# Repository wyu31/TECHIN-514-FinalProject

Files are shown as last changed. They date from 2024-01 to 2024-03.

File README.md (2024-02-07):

# TECHIN-514-FinalProject
This GitHub repository is for my TECHIN-514 final project and all my related files will be uploaded and updated to it.

## System Architecture with Diagram
### Slide 1 - Introduction
**Project Title**  
Finger Drumbeat

**Explanation**  
This is an IoT device set to add drum beats using hand gestures, allowing users to engage in existing music.

Generally, I want to achieve:
1. Different **fingertip accelerations** produce different **Stepper-motor-driven gauge needle** swing accelerations and different drum beat loudnesses (with **Speaker & Amplifier**).
2. Different **components of the drum** (Bass Drum, Tom-Tom Drum, Snare drum, Crash Cymbal, Ride Cymbal, Hi-Hat) are played under different **gestures**.
3. **OLED** screen displays the component currently being played.
4. **LED Array** randomly displays rhythm animation
5. **Button** can switch the random animations on the LED Array

**General Sketch**  
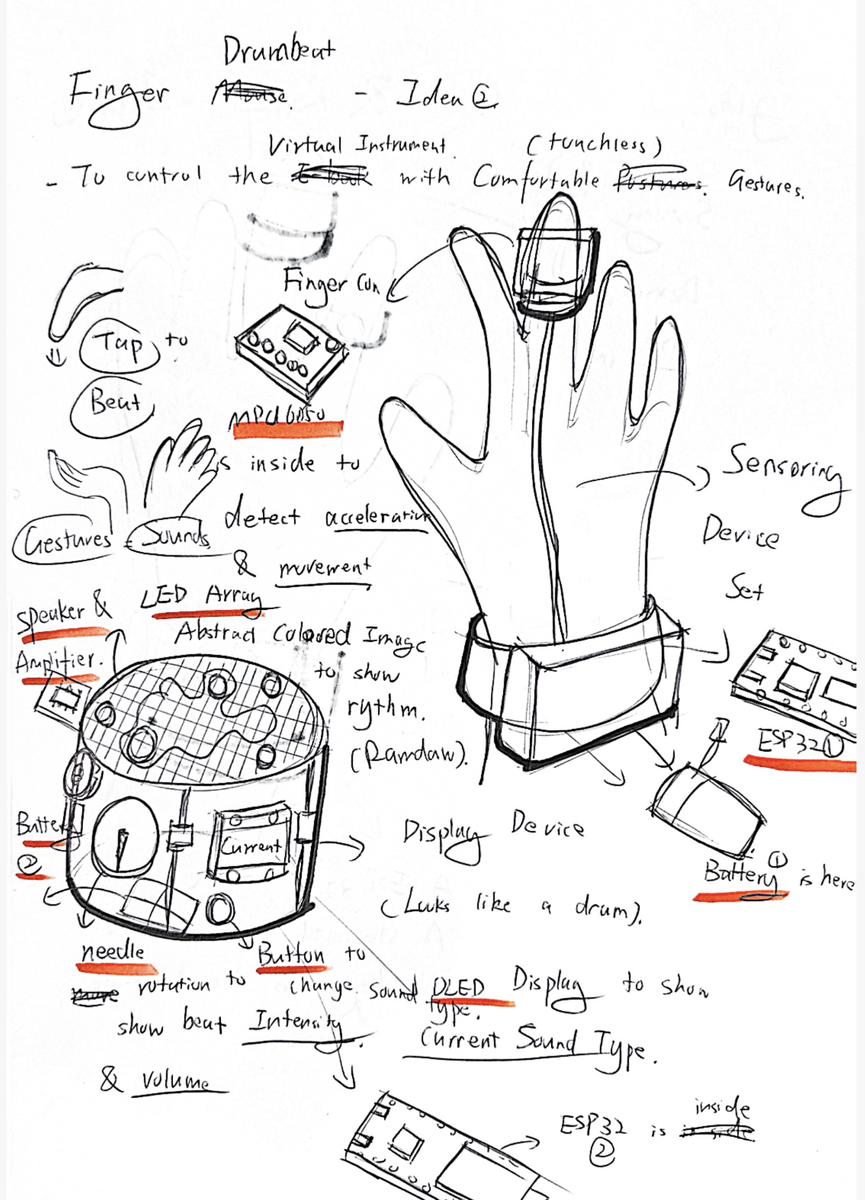
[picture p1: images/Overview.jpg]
Image of the general sketch


### Slide 2 - Sensor Device
In this part, the enclosure is divided into two parts: fingertip and wrist. The fingertip enclosure contains the MPU6050, and the wrist enclosure contains the ESP32 processor and battery.

MPU6050 and ESP32 will detect and analyze diffeerent fingertip accelerations for different needle swing accelerations and drumbeat volumes.

MPU6050 and ESP32 will also detect and analyze different gestures as different drum components (such as ass Drum, Tom-Tom Drum, Snare drum, Crash Cymbal, Ride Cymbal, Hi-Hat).

1. Sensor: MPU6050 accelerometer and gyroscope to detect hand accelerations and gestures
2. Processor: XIAO-ESP32-S3
3. Wireless link:  XIAO-ESP32-S3 has a bluetooth module inside
4. Power: Lithium Ion Polymer Battery Ideal For Feathers
5. Enclosure:(Shown on Sketch) 
6. Custom PCB: will be based on the sensor, battery & enclosure size

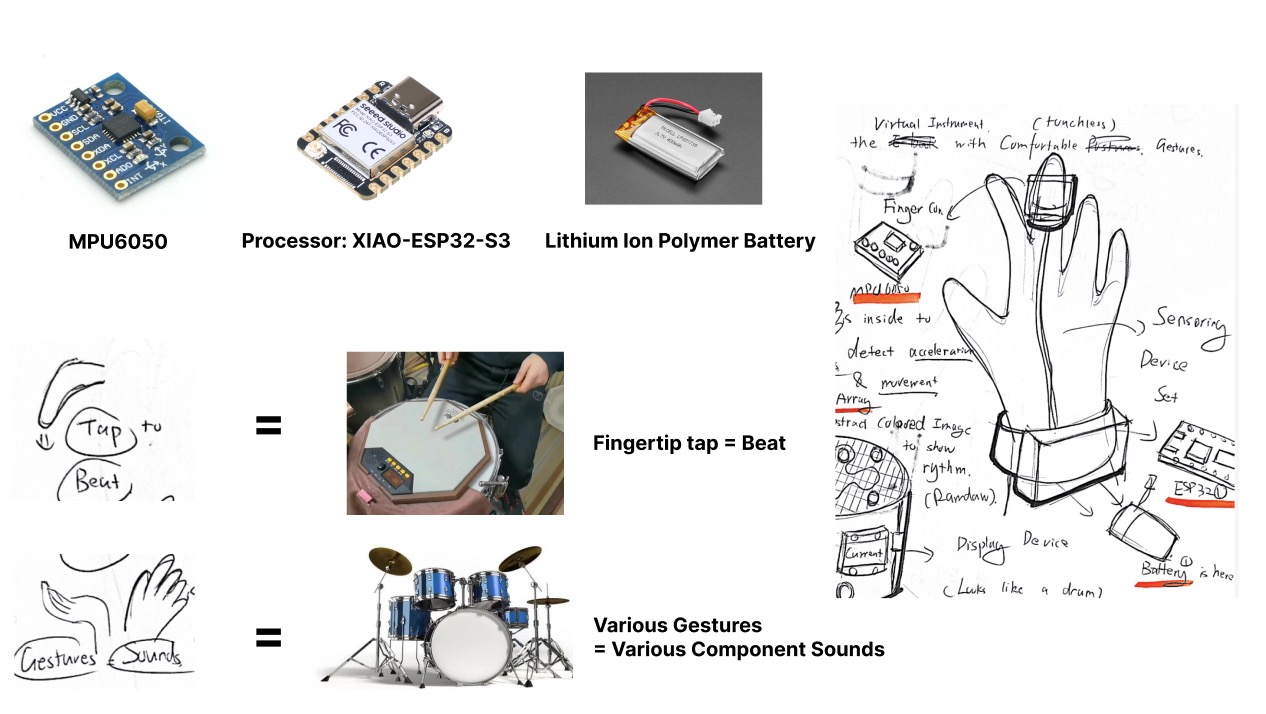
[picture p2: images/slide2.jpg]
Image of the slide2


### Slide 3 - Display Device
The shaking acceleration of the stepper motor pointer depends on the acceleration of the finger; the intensity of the sound and enhanced sound also depends on the acceleration of the finger.

The LED array will randomly play flowing animations to reflect the linkage of audio and vision; touch the button to switch animations.

The OLED screen will display the names of the components of the drum set selected under the current gesture.

1. Stepper-motor-driven gauge needle:  Show the intensity and volume of the drumming. More forceful gestures could push the needle further, indicating a higher intensity and volume.
2. Processor: XIAO-ESP32-S3
3. LED Array:  LED Array randomly displays rhythm animation
4. Button: Capacitive touch button to switch animations
5. Enclosure:(Shown on Sketch) 
6. Custom PCB: will be based on the sensors & enclosure size
7. Battery: Lithium Ion Polymer Battery Ideal For Feathers
8. Displays: OLED - Text info of the type of drum sound currently selected

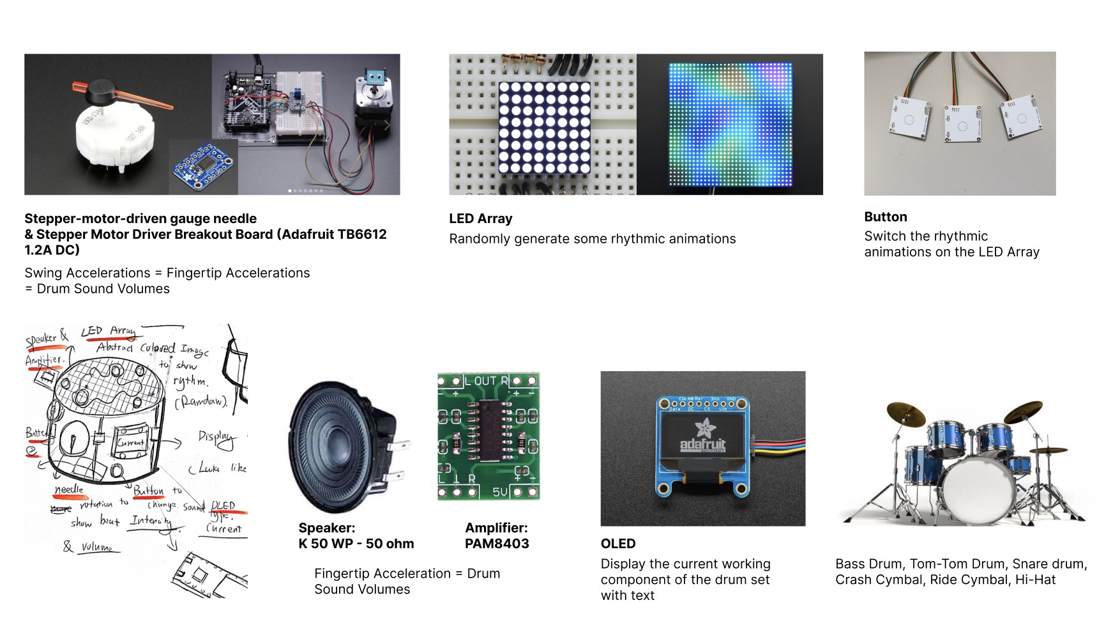
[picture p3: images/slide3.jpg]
Image of the slide3


### Slide 4 - Figure & Diagram

**Device Communication Figure**
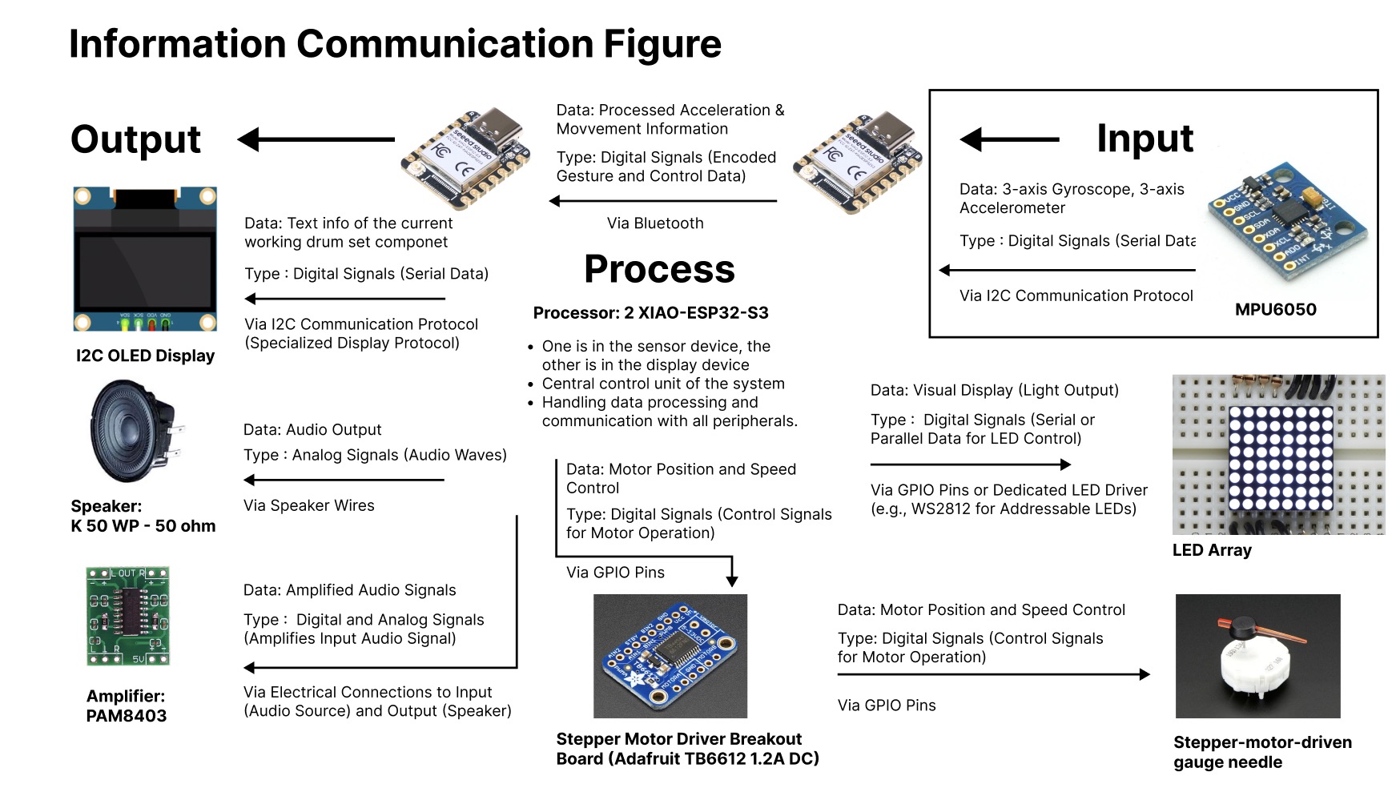
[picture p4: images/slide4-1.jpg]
Image of the communication figure


**Workflow Diagram**
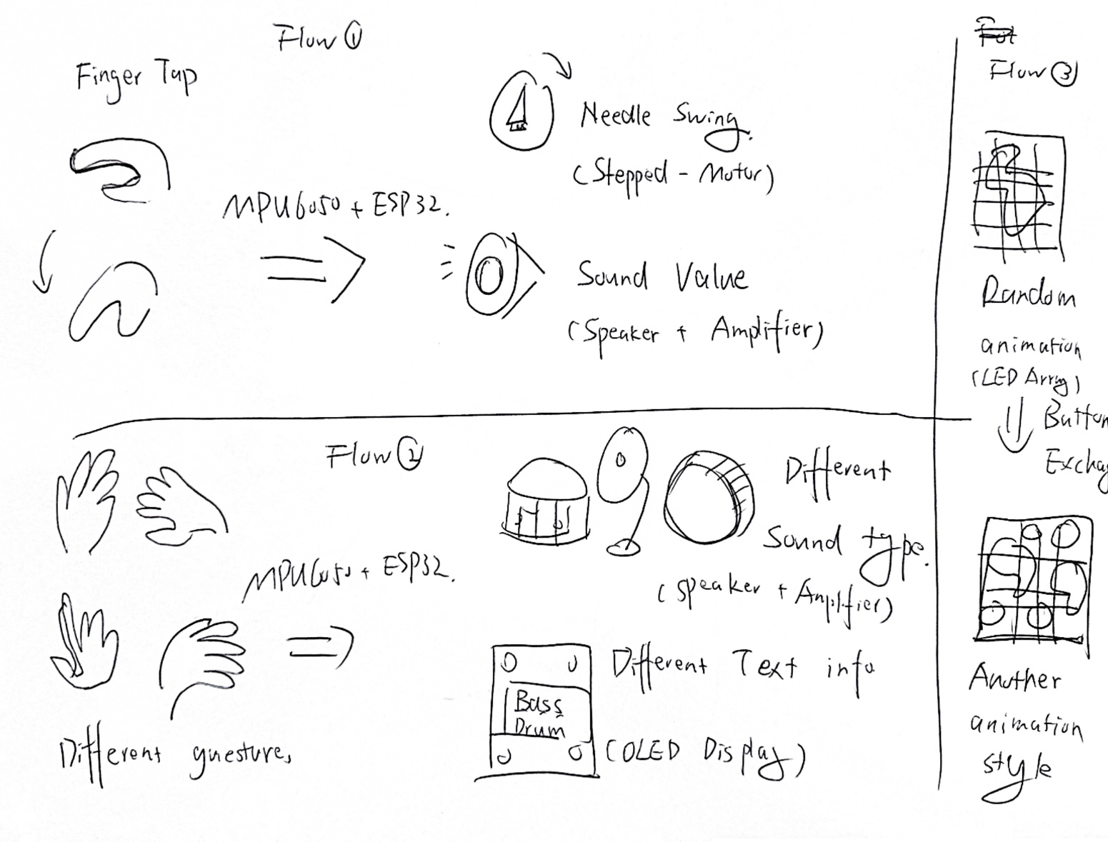
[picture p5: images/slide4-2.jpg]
Image of the workflow diagram


**Display Device Arch**
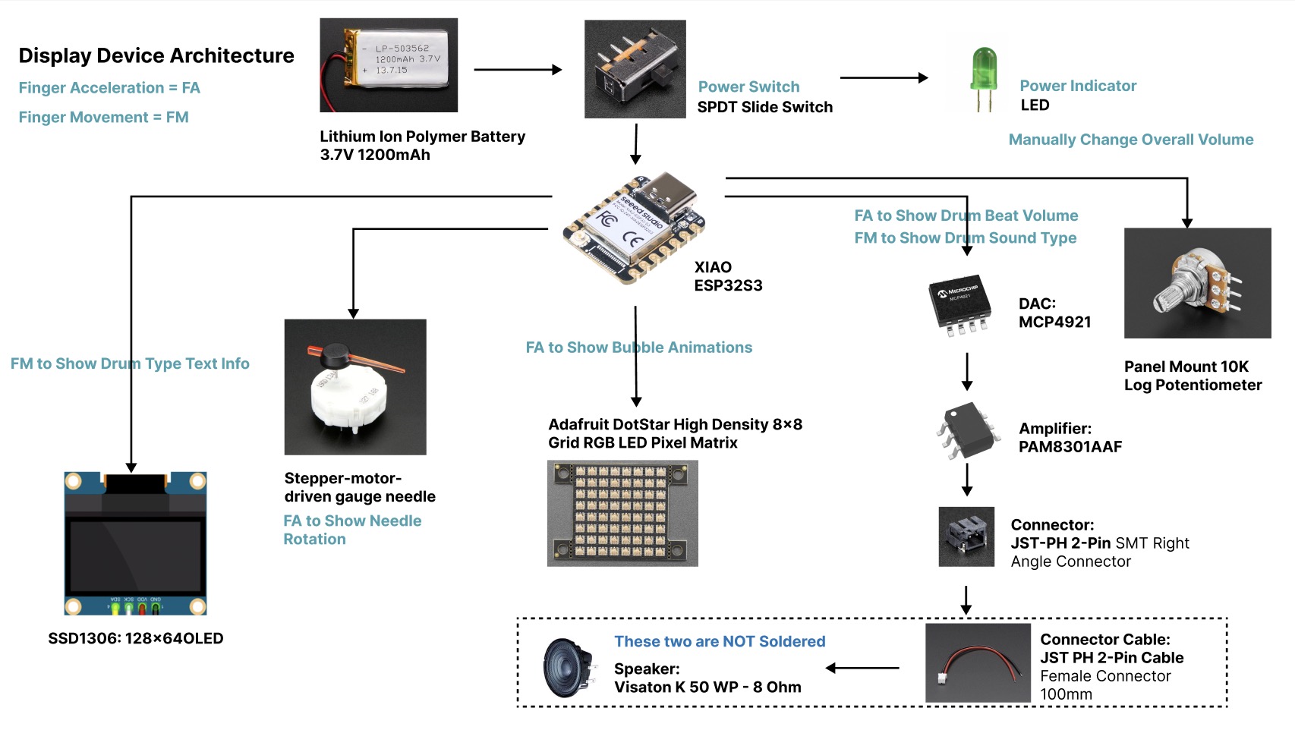
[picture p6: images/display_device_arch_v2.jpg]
Image of arch


## PCB Lab
### Processer: XIAO-ESP32-S3
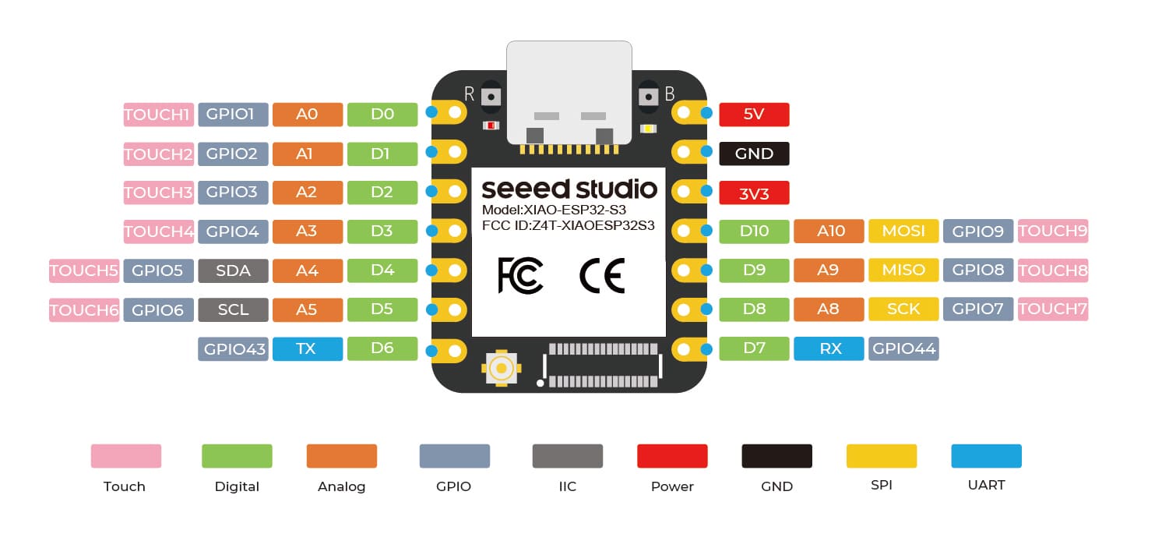
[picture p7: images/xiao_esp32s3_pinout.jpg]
Image of the xiao-esp32-s3 pinout


### Sensor: XIAO-ESP32-S3
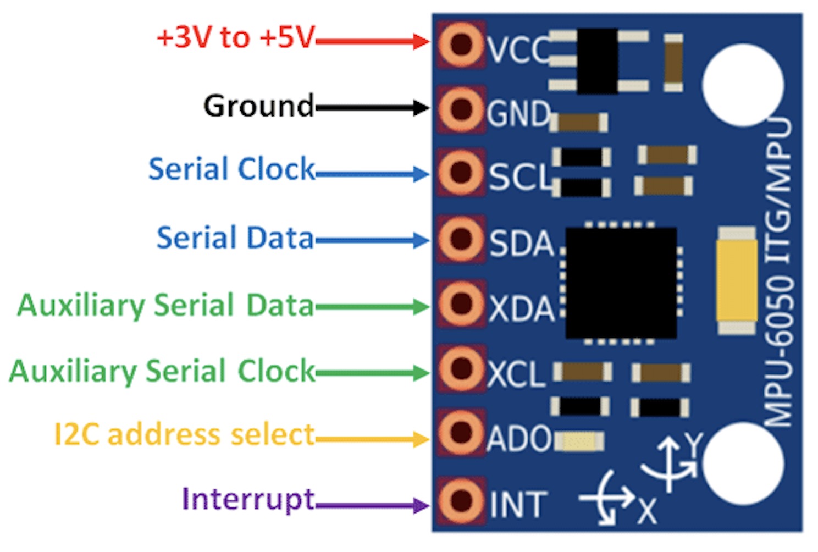
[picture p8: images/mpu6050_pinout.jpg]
Image of the mpu6050 pinout


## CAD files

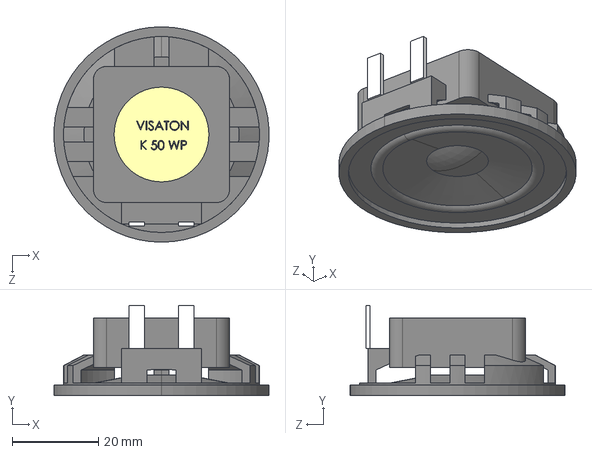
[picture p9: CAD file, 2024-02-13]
pcb_lab_display_Feb 4_backup/3D_model/Speaker Visaton k50 wp8.STEP
49.9 x 21.0 x 50.0 mm

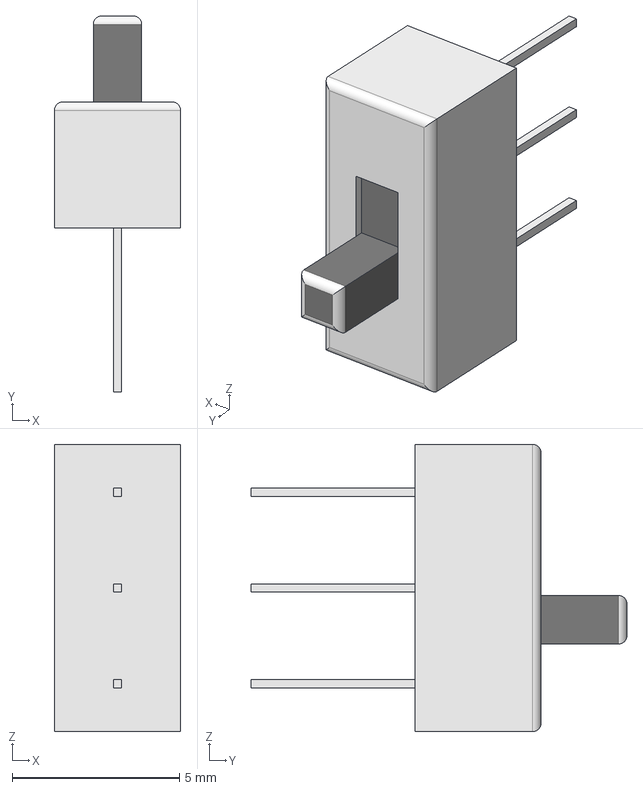
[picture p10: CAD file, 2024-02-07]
pcb_lab_Feb 14/3D_model/Slide switch.step
3.77 x 11.2 x 8.59 mm

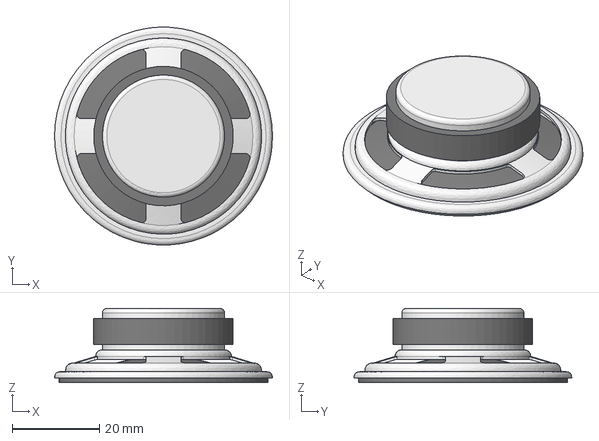
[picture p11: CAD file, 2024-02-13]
pcb_lab_display_Feb 4_backup/3D_model/Visaton K50 v7.step
50.0 x 50.0 x 17.0 mm

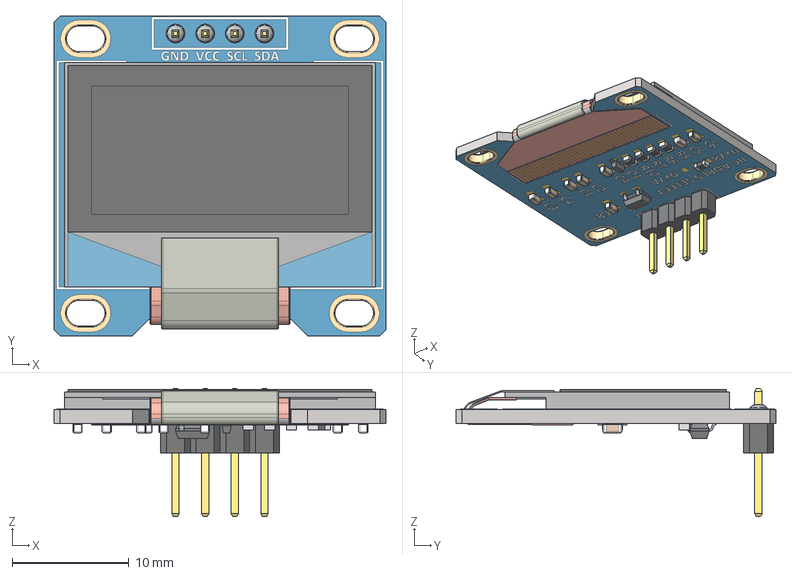
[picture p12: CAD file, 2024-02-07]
pcb_lab_Feb 14/3D_model/OLED 0.96'' 128x64.stp
28.4 x 27.4 x 11.0 mm
SOT-23_TOR
RES_CR16_MTK_1 x 4
RES_CR16_MTK
SOD323F_DIO

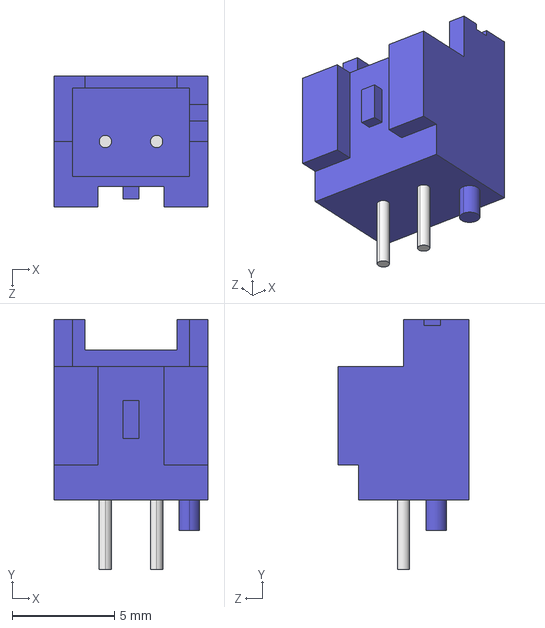
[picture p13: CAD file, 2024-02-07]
pcb_lab_Feb 14/3D_model/B02B-XASK-1-A.STEP
7.50 x 12.2 x 6.40 mm

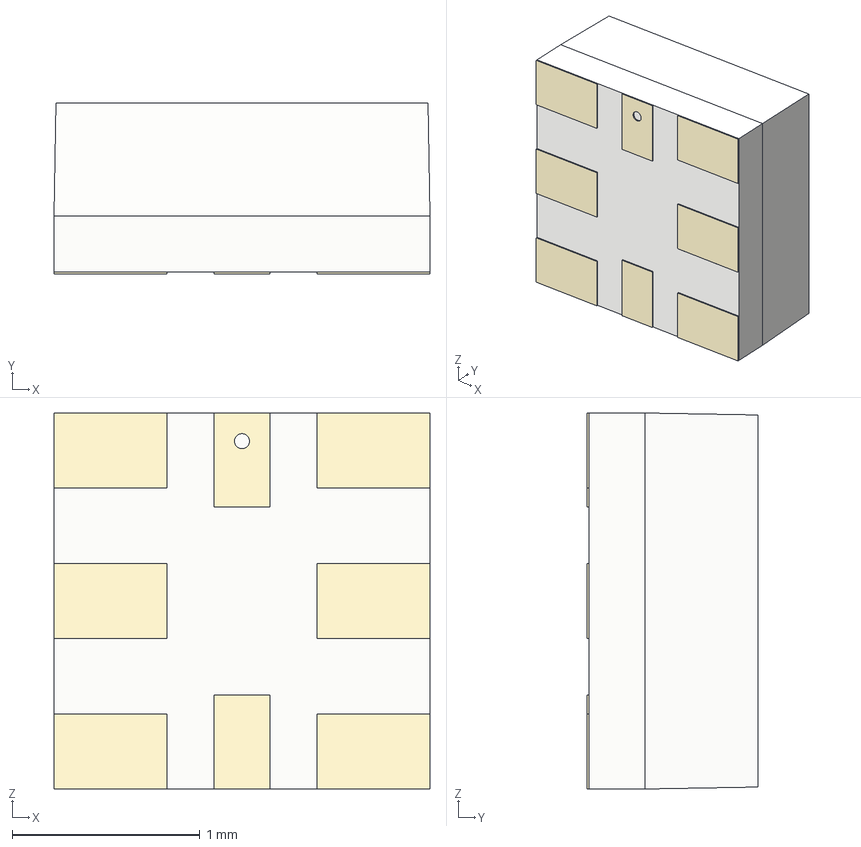
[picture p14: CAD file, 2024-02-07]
pcb_lab_Feb 14/3D_model/APA102 2020 LED.step
2.00 x 0.91 x 2.00 mm

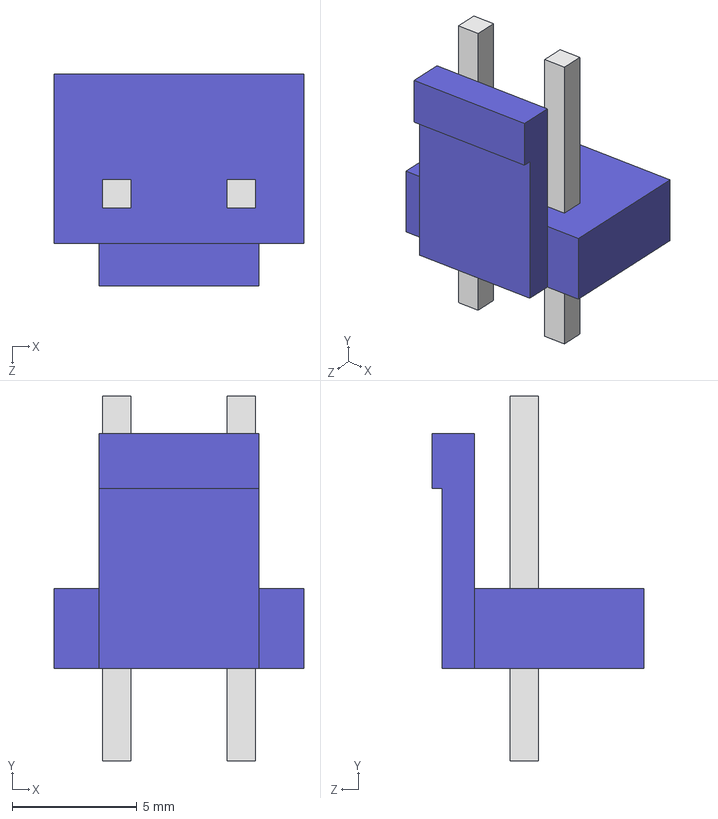
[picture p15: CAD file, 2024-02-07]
pcb_lab_Feb 14/3D_model/B02P-NV.STEP
10.0 x 14.6 x 8.50 mm

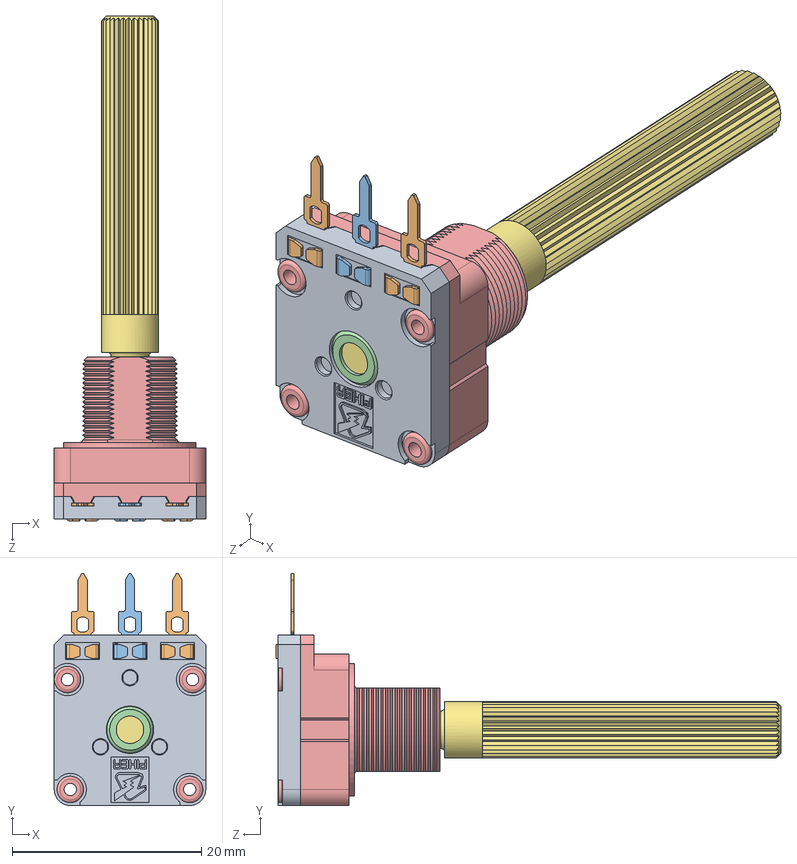
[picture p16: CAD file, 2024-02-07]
pcb_lab_Feb 14/3D_model/PC16SH10IP06.STEP
16.0 x 24.5 x 53.3 mm
PORTARESISTENCIA
TERMINAL DERECHO
TERMINAL IZQUIERDO
COLECTOR
PORTACURSOR
CARCASA
RESISTENCIA
EJE_Predeterminada

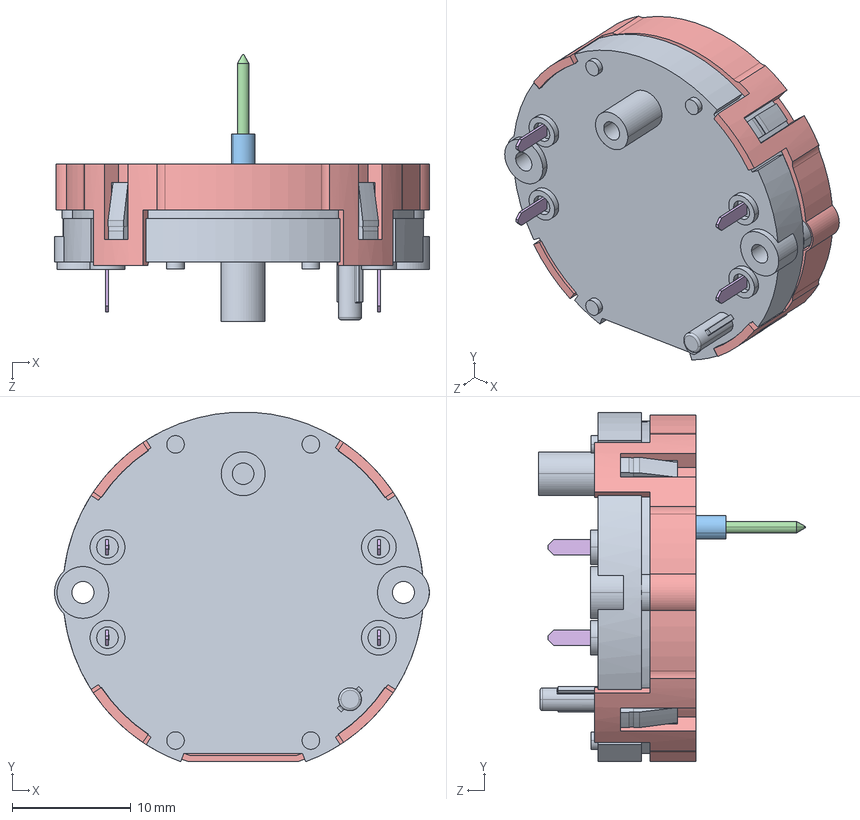
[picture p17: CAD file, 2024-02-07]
pcb_lab_Feb 14/3D_model/Stepper Motor X27.STEP
31.6 x 29.4 x 22.5 mm
STEPPER_X27_Boden
STEPPER_X27_Rotor
STEPPER_X27_Zahnrad_Abtrieb
STEPPER_X27_Achse
STEPPER_X27_Deckel
STEPPER_X27_Magnetkern x 2
STEPPER_X27_Spule x 2
STEPPER_X27_Anker
STEPPER_X27_Zahnrad_Mitte

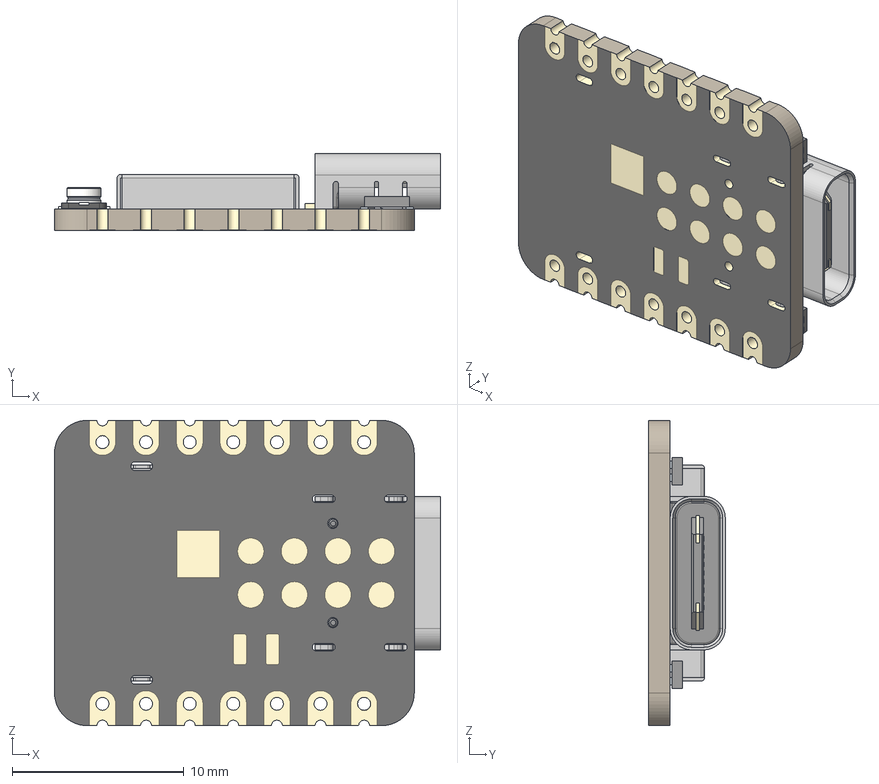
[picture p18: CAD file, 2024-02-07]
pcb_lab_Feb 14/3D_model/XIAO-ESP32S3 v2.step
22.5 x 4.46 x 17.8 mm
BOSS-EXTRUDE14_8_
BOSS-EXTRUDE7_4_
BOSS-EXTRUDE7_3_
BOSS-EXTRUDE14_4_
BOSS-EXTRUDE14_2_
BOSS-EXTRUDE14_11_
BOSS-EXTRUDE7_7_
BOSS-EXTRUDE14_9_
BOSS-EXTRUDE14_3_
BOSS-EXTRUDE14_7_
MIRROR2
BOSS-EXTRUDE14_5_
BOSS-EXTRUDE14_12_
BOSS-EXTRUDE7_8_
BOSS-EXTRUDE7_1_
BOSS-EXTRUDE14_10_
BOSS-EXTRUDE7_9_
BOSS-EXTRUDE14_6_
BOSS-EXTRUDE14_1_
BOSS-EXTRUDE7_6_
BOSS-EXTRUDE7_2_
CUT-EXTRUDE5
BOSS-EXTRUDE7_5_
Shield
Pins x 2
U.FL-R-SMT-1_10_ v1

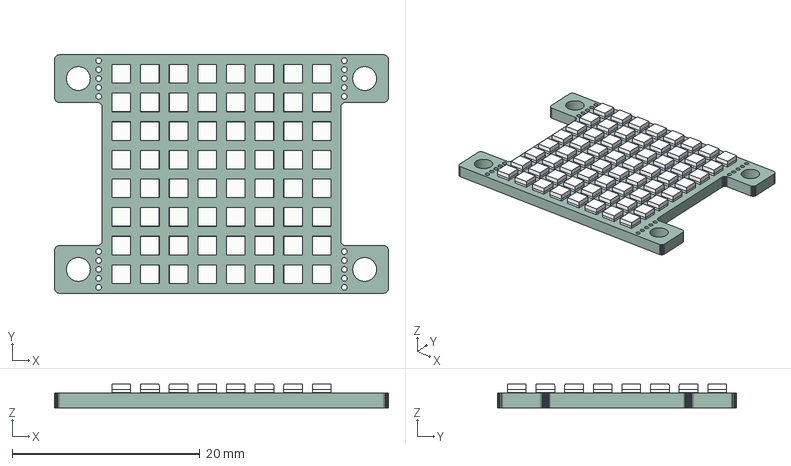
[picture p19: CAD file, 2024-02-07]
pcb_lab_Feb 14/3D_model/Adafruit DotStar 2020 8x8 Matrix .step
35.6 x 25.4 x 2.55 mm
Adafruit DotStar 2020 8x8 Matrix PCB

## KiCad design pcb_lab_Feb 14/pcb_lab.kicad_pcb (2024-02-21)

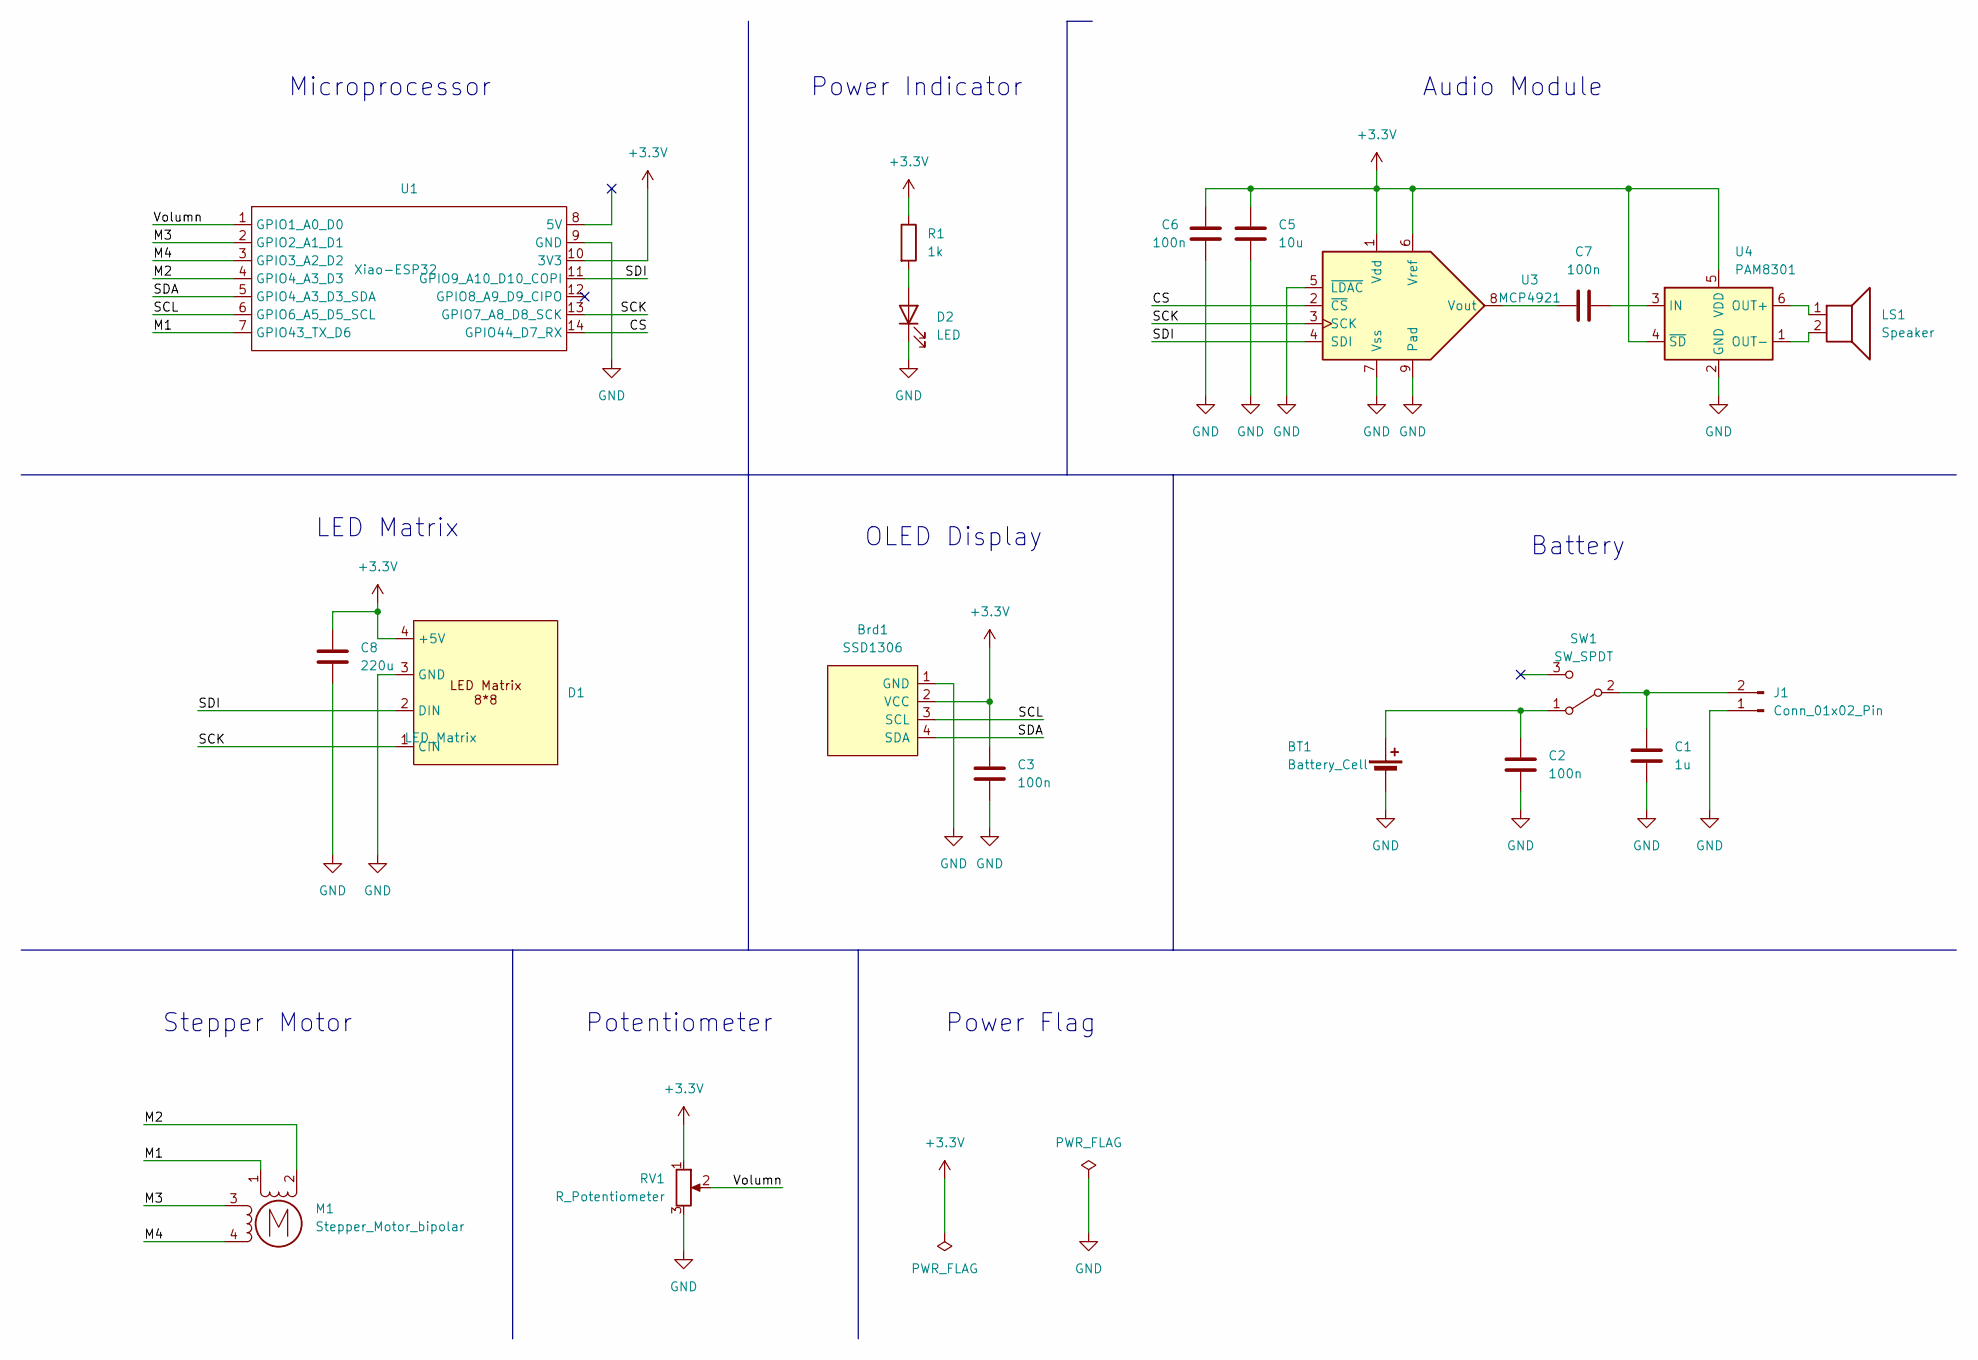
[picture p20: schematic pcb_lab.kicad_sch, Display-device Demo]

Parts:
BT1: Battery_Cell; JST_XA_B02B-XASK-1-A_1x02_P2.50mm_Vertical
Brd1: SSD1306; 128x64OLED
C1: 1u; C_0603_1608Metric_Pad1.08x0.95mm_HandSolder
C2, C3, C6, C7: 100n; C_0603_1608Metric_Pad1.08x0.95mm_HandSolder
C5: 10u; CP_EIA-1608-08_AVX-J_Pad1.25x1.05mm_HandSolder
C8: 220u; CP_Radial_D6.3mm_P2.50mm
D1: LED_Matrix; PinSocket_1x04_P2.54mm_Horizontal
D2: LED; LED_0603_1608Metric_Pad1.05x0.95mm_HandSolder
J1: Conn_01x02_Pin; JST_NV_B02P-NV_1x02_P5.00mm_Vertical
LS1: Speaker; JST_NV_B02P-NV_1x02_P5.00mm_Vertical
M1: Stepper_Motor_bipolar; X27_stepper_motor
R1: 1k; R_0603_1608Metric_Pad0.98x0.95mm_HandSolder
RV1: R_Potentiometer; Potentiometer_Piher_PC-16_Single_Horizontal
SW1: SW_SPDT; JST_EH_B3B-EH-A_1x03_P2.50mm_Vertical
U1: Xiao-ESP32; XIAO_ESP32_SENSE
U3: MCP4921; DFN-8-1EP_3x2mm_P0.5mm_EP1.3x1.5mm
U4: PAM8301; SOT-23-6

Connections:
+3.3V: Brd1.2 (VCC), C3.1, C5.1, C6.1, C8.1, D1.4 (+5V), R1.1, RV1.1, U1.10 (3V3), U3.1 (Vdd), U3.6 (Vref), U4.4 (~SD), U4.5 (VDD)
/CS: U1.14 (GPIO44_D7_RX), U3.2 (~CS)
/M1: M1.1, U1.7 (GPIO43_TX_D6)
/M2: M1.2 (-), U1.4 (GPIO4_A3_D3)
/M3: M1.3, U1.2 (GPIO2_A1_D1)
/M4: M1.4, U1.3 (GPIO3_A2_D2)
/SCK: D1.1 (CIN), U1.13 (GPIO7_A8_D8_SCK), U3.3 (SCK)
/SCL: Brd1.3 (SCL), U1.6 (GPIO6_A5_D5_SCL)
/SDA: Brd1.4 (SDA), U1.5 (GPIO4_A3_D3_SDA)
/SDI: D1.2 (DIN), U1.11 (GPIO9_A10_D10_COPI), U3.4 (SDI)
/Volumn: RV1.2, U1.1 (GPIO1_A0_D0)
GND: BT1.2 (-), Brd1.1 (GND), C1.2, C2.2, C3.2, C5.2, C6.2, C8.2, D1.3 (GND), D2.1 (K), J1.1, RV1.3, U1.9 (GND), U3.5 (~LDAC), U3.7 (Vss), U3.9 (Pad), U4.2 (GND)
unnamed: BT1.1 (+), C2.1, SW1.1 (A)
unnamed: D2.2 (A), R1.2
unnamed: C1.1, J1.2, SW1.2 (B)
unnamed: C7.1, U3.8 (Vout)
unnamed: C7.2, U4.3 (IN)
unnamed: LS1.1, U4.6 (OUT+)
unnamed: LS1.2, U4.1 (OUT-)

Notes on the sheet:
Audio Module
Power Flag
Stepper Motor
Microprocessor
Power Indicator
Battery
OLED Display
Potentiometer
LED Matrix

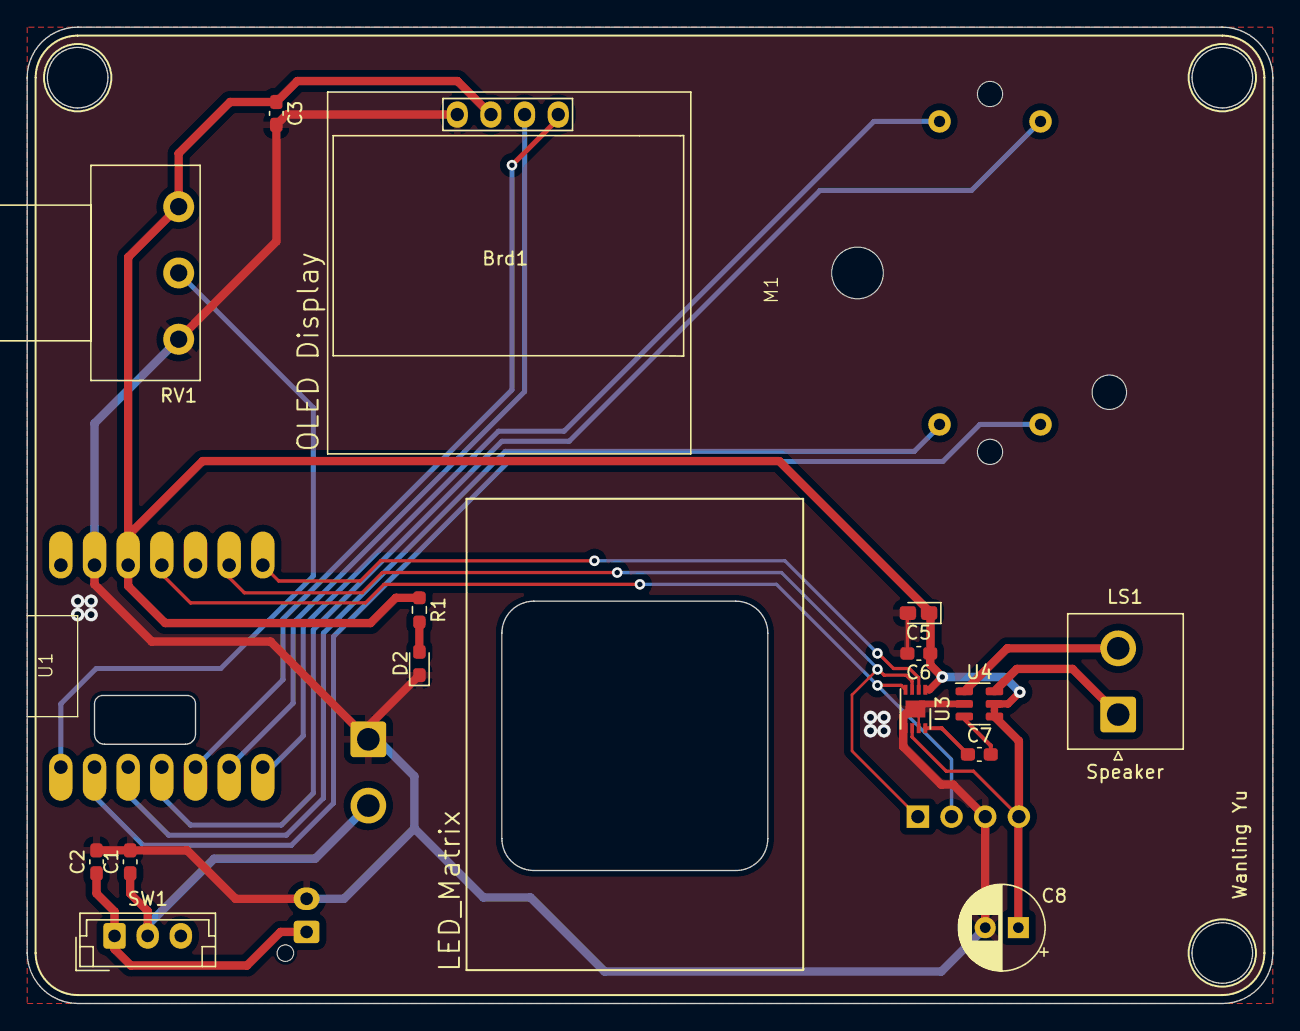
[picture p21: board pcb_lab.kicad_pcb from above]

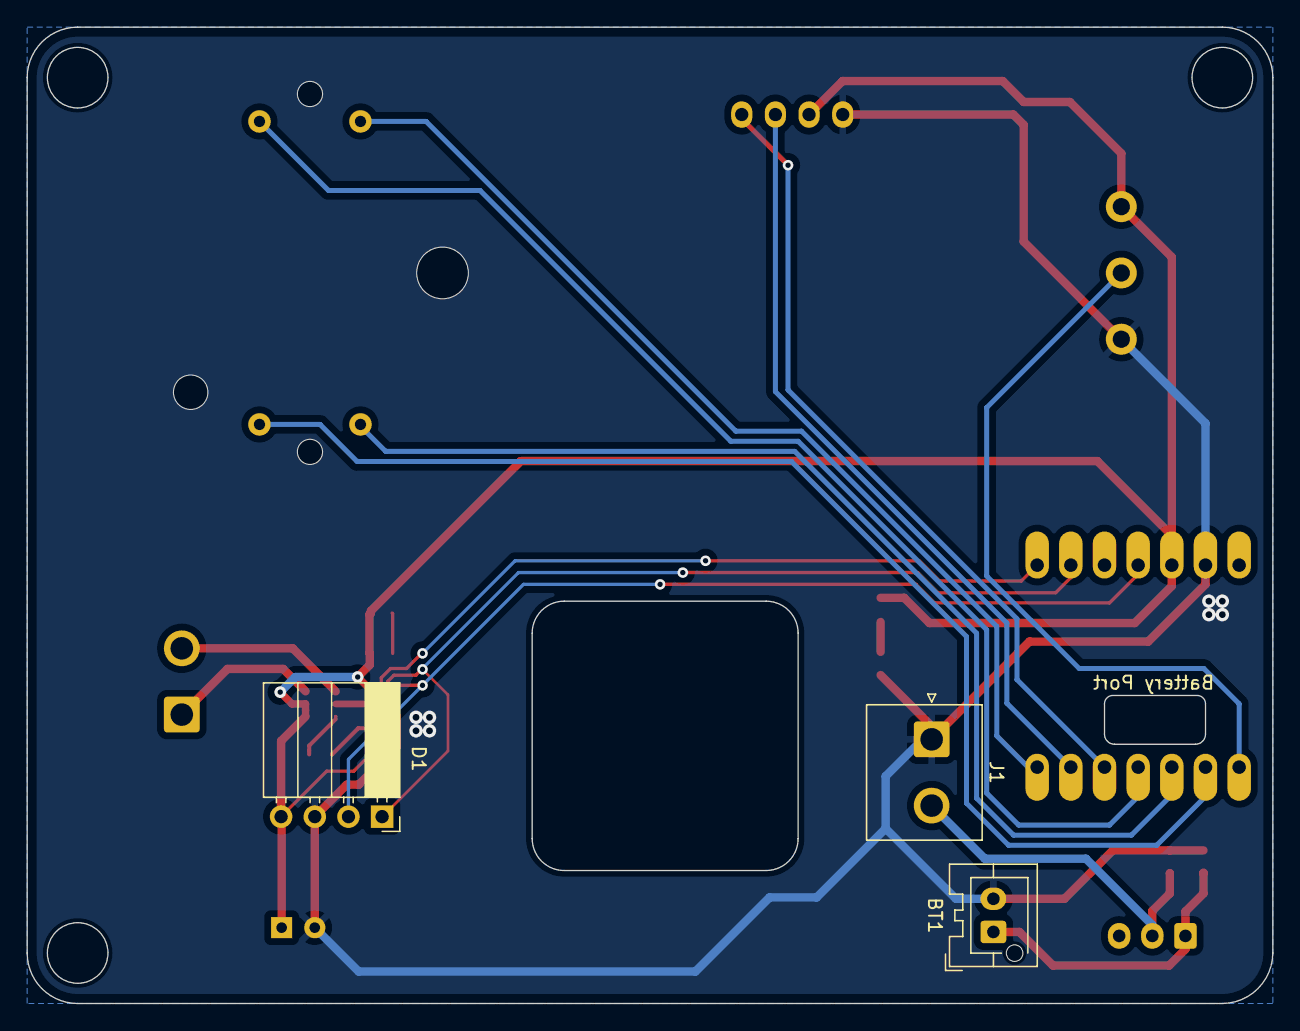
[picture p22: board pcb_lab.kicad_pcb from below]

Board: 2 copper layers, 94.0 x 73.7 mm, 20 parts (3 on the bottom side), 19 nets.

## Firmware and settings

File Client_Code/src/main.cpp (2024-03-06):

#include <Arduino.h>
#include <BLEDevice.h>
#include <BLEUtils.h>
#include <BLEScan.h>
#include <BLEAdvertisedDevice.h>

#include <Wire.h>
#include <Adafruit_GFX.h>
#include <Adafruit_SSD1306.h>
#include <Stepper.h>

#include "Hi_Hat_data.h"
#include "Snare_Drum_data.h"
#include "Bass_Drum_data.h"
#include "Crash_Cymbal_data.h"

#define SCREEN_WIDTH 128 // OLED display width, in pixels
#define SCREEN_HEIGHT 64 // OLED display height, in pixels
#define OLED_RESET     -1 // Reset pin # (or -1 if sharing Arduino reset pin)

// Declaration for two SSD1306 displays connected to I2C (SDA, SCL pins)
Adafruit_SSD1306 display1(SCREEN_WIDTH, SCREEN_HEIGHT, &Wire, OLED_RESET);
Adafruit_SSD1306 display2(SCREEN_WIDTH, SCREEN_HEIGHT, &Wire, OLED_RESET);

// Global flag to ensure sound is played once per gesture + drum beat combination
bool soundPlayed = false;

// BLE UUIDs
#define SERVICE_UUID        "89d32ebb-e935-47d3-9877-817c75c12572"
#define CHARACTERISTIC_UUID "10c5f81b-952e-4e3d-84a7-ab9e8ec83683"

// Stepper motor setup
const int stepsPerRevolution = 400; // Change this per your motor's specification
// Example GPIO pins; replace D6, D3, D1, D2 with actual GPIO numbers used
Stepper myStepper(stepsPerRevolution, D6, D3, D1, D2);

// Sound Playback variables
const int csPin = 44; // Chip Select pin for MCP4921 DAC
const int sckPin = 7;  // SPI Clock pin
const int mosiPin = 9; // SPI MOSI (Master Out Slave In) pin
const int misoPin = 8; // Or set to -1 if you prefer to signify it's not used
const int potPin = A1;  // Analog pin for reading the potentiometer
SPIClass *hspi = new SPIClass(HSPI);

float volumeMultiplier = 0.25;

// Function prototypes
void updateDisplay1WithGesture(int gesture);
void updateDisplay2WithAcclZ(float AcclZ);
void sendValueToDAC(uint16_t value);
void playSound(const String& soundName);

struct DrumBeatData {
  int gesture;
  float AcclZ;
};

BLEUUID serviceUUID(SERVICE_UUID);
BLEUUID charUUID(CHARACTERISTIC_UUID);
boolean doConnect = false;
boolean connected = false;
boolean doScan = false;
BLERemoteCharacteristic* pRemoteCharacteristic;
BLEAdvertisedDevice* myDevice;


String currentGestureText = "";
boolean drumBeatActive = false;

class MyClientCallback : public BLEClientCallbacks {
  void onConnect(BLEClient* pclient) override {
    connected = true;
    String text = "READY";
    display2.clearDisplay();
    display2.setTextSize(2); // Choose an appropriate text size

    // Dynamically calculate the width of the text at the current font size
    int16_t textWidth = 6 * text.length() * 2; // 6 is the approx width of a character at textSize=1, *2 for textSize=2
    int16_t x = (SCREEN_WIDTH - textWidth) / 2;
    int16_t y = (SCREEN_HEIGHT / 2) - 8; // Half the height of the display minus half the height of text
    
    display2.setCursor(x,y);
    display2.print(text);
    display2.display();
  }

  void onDisconnect(BLEClient* pclient) override {
    connected = false;
    // Optionally, you can also update the display upon disconnection
    display2.clearDisplay();
    display2.setTextSize(1); // Choose an appropriate text size
    display2.setCursor(0,0); // Start at top-left corner
    display2.print("Disconnected");
    display2.display();
  }
};


class MyAdvertisedDeviceCallbacks: public BLEAdvertisedDeviceCallbacks {
  void onResult(BLEAdvertisedDevice advertisedDevice) override {
    if (advertisedDevice.haveServiceUUID() && advertisedDevice.isAdvertisingService(serviceUUID)) {
      Serial.println("Found our device!");
      BLEDevice::getScan()->stop();
      myDevice = new BLEAdvertisedDevice(advertisedDevice);
      doConnect = true;
      doScan = false;
    }
  }
};

void notifyCallback(
  BLERemoteCharacteristic* pBLERemoteCharacteristic,
  uint8_t* pData,
  size_t length,
  bool isNotify) {
    if (length == sizeof(DrumBeatData)) {
        DrumBeatData receivedData;
        memcpy(&receivedData, pData, sizeof(DrumBeatData));
        updateDisplay1WithGesture(receivedData.gesture); // Update display1 with gesture info
        updateDisplay2WithAcclZ(receivedData.AcclZ); // Update display2 based on AcclZ
    }
}

bool connectToServer() {
    Serial.println("Connecting to server...");
    BLEClient* pClient = BLEDevice::createClient();
    pClient->setClientCallbacks(new MyClientCallback());

    if (pClient->connect(myDevice)) {
        Serial.println("Connected to server");
        BLERemoteService* pRemoteService = pClient->getService(serviceUUID);
        if (pRemoteService == nullptr) {
          Serial.println("Failed to find our service UUID");
          return false;
        }
        pRemoteCharacteristic = pRemoteService->getCharacteristic(charUUID);
        if (pRemoteCharacteristic == nullptr) {
          Serial.println("Failed to find our characteristic UUID");
          return false;
        }
        if (pRemoteCharacteristic->canNotify())
          pRemoteCharacteristic->registerForNotify(notifyCallback);

        return true;
    } else {
        Serial.println("Failed to connect");
        return false;
    }
}

// Global variables to manage the animation state
bool displayDrumBeat = false; // Global variable to track display state for "DrumBeat"
unsigned long previousMillis = 0; // Stores the last time the display was updated
const long interval = 500; // Interval at which to update the animation (milliseconds)
bool isDisplayOn = false; // Tracks the display state for toggling text
int animationFrame = 0; // Tracks the current frame of the animatione

void updateDisplay1WithGesture(int gesture) {
    String gestureText;
    switch (gesture) {
        case 1: gestureText = "HI HAT"; break;
        case 2: gestureText = "SNARE DRUM"; break;
        case 3: gestureText = "BASS DRUM"; break;
        case 4: gestureText = "CRASH CYMBAL"; break;
        default: gestureText = "INTERVAL";
    }

    display1.clearDisplay();
    display1.setTextSize(2); // Assuming this makes each character approximately 12 pixels wide

    // Dynamically calculate the width of the text at the current font size
    int16_t textWidth = 6 * gestureText.length() * 2; // 6 is the approx width of a character at textSize=1, *2 for textSize=2
    int16_t x = (SCREEN_WIDTH - textWidth) / 2;
    int16_t y = (SCREEN_HEIGHT / 2) - 8; // Half the height of the display minus half the height of text

    display1.setCursor(x, y);
    display1.println(gestureText);
    currentGestureText = gestureText;
    display1.display();
}

void updateDisplay2WithAcclZ(float AcclZ) {
    unsigned long currentMillis = millis();

    // Check if the display should blink
    if (currentMillis - previousMillis >= interval) {
        previousMillis = currentMillis;
        isDisplayOn = !isDisplayOn;
    }

    if (AcclZ < 0) {
        if (!displayDrumBeat) { // If entering the "DRUM BEAT" phase
            myStepper.step(stepsPerRevolution); // Rotate stepper motor one revolution forward
            displayDrumBeat = true; // Mark that we are in the "DRUM BEAT" phase
        }
        drumBeatActive = true;
        // Blink "DRUM BEAT" text
        display2.clearDisplay();
        display2.setTextSize(2);
        if (isDisplayOn) {
            display2.setCursor((SCREEN_WIDTH - 9 * 12) / 2, (SCREEN_HEIGHT / 2) - 8);
            display2.print("DRUM BEAT");
        }
        display2.display();
    } else {
        if (displayDrumBeat) { // If exiting the "DRUM BEAT" phase
            myStepper.step(-stepsPerRevolution); // Rotate stepper motor one revolution backward
            displayDrumBeat = false; // Reset for the next phase
            isDisplayOn = true; // Make sure "STICK UP" is displayed without blinking
        }

        // Display "STICK UP" text without blinking
        drumBeatActive = false;
        soundPlayed = false;
        display2.clearDisplay();
        display2.setTextSize(2);
        display2.setCursor((SCREEN_WIDTH - 8 * 12) / 2, (SCREEN_HEIGHT / 2) - 8);
        display2.print("STICK UP");
        display2.display();
    }
}

void setup() {
  Serial.begin(115200);
  BLEDevice::init("");


  // Initialize first OLED with I2C addr 0x3C (128x64)
  if (!display1.begin(SSD1306_SWITCHCAPVCC, 0x3C)) {
    Serial.println(F("SSD1306 allocation failed for display 1"));
    for (;;); // Don't proceed, loop forever
  }

  // Initialize second OLED with I2C addr 0x3D (128x64)
  if (!display2.begin(SSD1306_SWITCHCAPVCC, 0x3D)) {
    Serial.println(F("SSD1306 allocation failed for display 2"));
    for (;;); // Don't proceed, loop forever
  }

  // Clear the buffer for both displays
  display1.clearDisplay();
  display2.clearDisplay();

  // Setup display1 to show "Scanning..."
  display1.setTextSize(1);
  display1.setTextColor(SSD1306_WHITE);
  display1.setCursor(0, 0);
  display1.println("Scanning...");
  display1.display();

  // Setup display2 to show "Scanning..." as well
  display2.setTextSize(1);
  display2.setTextColor(SSD1306_WHITE);
  display2.setCursor(0, 0);
  display2.println("Scanning...");
  display2.display();

  // Setup stepper motor
  myStepper.setSpeed(60); // RPM

  // Initialize SPI for DAC
  hspi = new SPIClass(HSPI);
  hspi->begin(sckPin, misoPin, mosiPin, csPin); // Begin SPI with specified pins
  pinMode(csPin, OUTPUT);
  digitalWrite(csPin, HIGH); // Deselect the DAC
  

  // Start BLE scanning
  BLEScan* pBLEScan = BLEDevice::getScan();
  pBLEScan->setAdvertisedDeviceCallbacks(new MyAdvertisedDeviceCallbacks());
  pBLEScan->setInterval(1349);
  pBLEScan->setWindow(449);
  pBLEScan->setActiveScan(true);
  pBLEScan->start(5, false);
}

void loop() {
  if (doConnect) {
    doConnect = false;
    if (connectToServer()) {
      Serial.println("We are now connected to the BLE Server.");
    } else {
      Serial.println("We have failed to connect to the server; there is nothing more we will do.");
    }
  }


  if (connected) {
    // Play sound based on display content, if not already played
    if (!soundPlayed && drumBeatActive) {
      // Determine the sound to play based on the gesture
      if (currentGestureText == "HI HAT") {
        playSound("HI HAT");
      } else if (currentGestureText == "SNARE DRUM") {
        playSound("SNARE DRUM");
      } else if (currentGestureText == "BASS DRUM") {
        playSound("BASS DRUM");
      } else if (currentGestureText == "CRASH CYMBAL") {
        playSound("CRASH CYMBAL");
      }
      soundPlayed = true; // Prevent the sound from playing repeatedly
    }
  } else if (doScan) {
    BLEDevice::getScan()->start(0);  // 0 means continuous scanning
  }

  if (connected) {
    // If connected, this is where you can interact with the BLE server
  } else if (doScan) {
    BLEDevice::getScan()->start(0);  // 0 means continuous scanning
  }
}

void playSound(const String &soundName) {
    Serial.println("Playing Sound: " + soundName);
    size_t audioDataLength = 0;
    const uint16_t* audioData = nullptr;

    if (soundName == "HI HAT") {
        audioData = hiHatData;
        audioDataLength = sizeof(hiHatData) / sizeof(hiHatData[0]);
    } else if (soundName == "SNARE DRUM") {
        audioData = snareDrumData;
        audioDataLength = sizeof(snareDrumData) / sizeof(snareDrumData[0]);
    } else if (soundName == "BASS DRUM") {
        audioData = bassDrumData;
        audioDataLength = sizeof(bassDrumData) / sizeof(bassDrumData[0]);
    } else if (soundName == "CRASH CYMBAL") {
        audioData = crashCymbalData;
        audioDataLength = sizeof(crashCymbalData) / sizeof(crashCymbalData[0]);
    } else {
        return; // No matching sound
    }

    int sampleDelay = round(1000000.0 / 44100 / 2); // Assuming a sample rate of 44100 Hz

    for (size_t i = 0; i < audioDataLength; i++) {
        int adjustedSample = static_cast<int>((static_cast<float>(audioData[i] - 2048) * volumeMultiplier) + 2048);
        adjustedSample = max(0, min(adjustedSample, 4095));
        sendValueToDAC(static_cast<uint16_t>(adjustedSample));
        delayMicroseconds(sampleDelay);
    }
}

void sendValueToDAC(uint16_t value) {
    digitalWrite(csPin, LOW); // Select DAC
    value &= 0x0FFF; // Ensure value is within 12-bit range
    uint16_t dataToSend = 0x3000 | value; // Format data for DAC
    
    // Begin SPI transaction, send value, then end transaction
    hspi->beginTransaction(SPISettings(5000000, MSBFIRST, SPI_MODE0));
    hspi->transfer16(dataToSend);
    hspi->endTransaction();
    digitalWrite(csPin, HIGH); // Deselect DAC
}

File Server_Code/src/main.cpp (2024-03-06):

#include <Wire.h>
#include <Adafruit_MPU6050.h>
#include <Adafruit_Sensor.h>
#include <SPI.h>
#include <Arduino.h>
#include <Arduino_APDS9960.h>
#include <BLEDevice.h>
#include <BLEServer.h>
#include <BLEUtils.h>
#include <BLE2902.h>
#include <stdlib.h>

#define SERVICE_UUID        "89d32ebb-e935-47d3-9877-817c75c12572"
#define CHARACTERISTIC_UUID "10c5f81b-952e-4e3d-84a7-ab9e8ec83683"

struct DrumBeatData {
  int gesture;
  float AcclZ;
};

Adafruit_MPU6050 mpu;
float alpha = 0.5; // Initial filter constant
float filteredAccelZ = 0;
float previousAccelZ = 0; // Store the previous raw AccelZ for dynamic alpha adjustment

BLEServer* pServer = NULL;
BLECharacteristic* pCharacteristic = NULL;
bool deviceConnected = false;
bool oldDeviceConnected = false;
unsigned long previousMillis = 0;
const long interval = 200; // Reduced interval for more frequent updates
int lastGestureId = 0;

class MyServerCallbacks : public BLEServerCallbacks {
    void onConnect(BLEServer* pServer) {
        deviceConnected = true;
    };

    void onDisconnect(BLEServer* pServer) {
        deviceConnected = false;
    }
};

void setup() {
    Serial.begin(115200);
    Serial.print("start");
    Wire.begin();
    
    if (!mpu.begin()) {
        Serial.println("Failed to find MPU6050 chip");
        while (1) {
            delay(10);
        }
    } else {
        Serial.println("MPU6050 is connected locally");
    }

    mpu.setAccelerometerRange(MPU6050_RANGE_8_G);
    mpu.setGyroRange(MPU6050_RANGE_500_DEG);
    mpu.setFilterBandwidth(MPU6050_BAND_21_HZ);
    Serial.println("MPU6050 initialized");

    if (!APDS.begin()) {
        Serial.println("Failed to initialize APDS9960");
    } else {
        Serial.println("APDS9960 is connected locally");
    }

    BLEDevice::init("Drumstick");
    pServer = BLEDevice::createServer();
    pServer->setCallbacks(new MyServerCallbacks());
    BLEService *pService = pServer->createService(SERVICE_UUID);
    pCharacteristic = pService->createCharacteristic(
        CHARACTERISTIC_UUID,
        BLECharacteristic::PROPERTY_READ |
        BLECharacteristic::PROPERTY_WRITE |
        BLECharacteristic::PROPERTY_NOTIFY
    );
    pCharacteristic->addDescriptor(new BLE2902());
    pService->start();
    BLEAdvertising *pAdvertising = BLEDevice::getAdvertising();
    pAdvertising->addServiceUUID(SERVICE_UUID);
    pAdvertising->setScanResponse(true);
    pAdvertising->setMinPreferred(0x06);
    pAdvertising->setMinPreferred(0x12);
    BLEDevice::startAdvertising();
    Serial.println("Drumstick is now advertising. Waiting for Player to connect...");
}

void loop() {
    sensors_event_t a, g, temp;
    mpu.getEvent(&a, &g, &temp);

    // Dynamically adjust alpha based on the change in acceleration
    float deltaAccelZ = fabs(a.acceleration.z - previousAccelZ);
    if (deltaAccelZ > 1.0) { // Threshold for significant movement, adjust as necessary
        alpha = 0.8; // More responsive to sudden changes
    } else {
        alpha = 0.2; // Smoother for minor changes
    }
    previousAccelZ = a.acceleration.z; // Update previousAccelZ

    filteredAccelZ = alpha * filteredAccelZ + (1.0 - alpha) * a.acceleration.z;
    Serial.println(filteredAccelZ);

    int gestureId = 0;
    if (APDS.gestureAvailable()) {
        switch (APDS.readGesture()) {
            case GESTURE_UP: gestureId = 1; break;
            case GESTURE_DOWN: gestureId = 2; break;
            case GESTURE_LEFT: gestureId = 3; break;
            case GESTURE_RIGHT: gestureId = 4; break;
            default: gestureId = 0;
        }
        Serial.print("Detected Gesture ID: ");
        Serial.println(gestureId);

        if (gestureId != 0) {
            lastGestureId = gestureId;
        }
    }

    if (deviceConnected) {
        DrumBeatData drumData = {lastGestureId, filteredAccelZ};
        uint8_t message[sizeof(DrumBeatData)];
        memcpy(message, &drumData, sizeof(DrumBeatData));

        unsigned long currentMillis = millis();
        if (currentMillis - previousMillis >= interval) {
            pCharacteristic->setValue(message,sizeof(DrumBeatData));
            pCharacteristic->notify();
            Serial.print("Notifying Player: Gesture ID: ");
            Serial.println(lastGestureId);
            Serial.println(filteredAccelZ);
            previousMillis = currentMillis;
        }
    }

    if (!deviceConnected && oldDeviceConnected) {
        delay(500);
        pServer->startAdvertising();
        oldDeviceConnected = deviceConnected;
        Serial.println("Drumstick starts advertising again");
    }

    if (deviceConnected && !oldDeviceConnected) {
        oldDeviceConnected = deviceConnected;
    }

    delay(100);
}

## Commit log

2024-01-18 Add pcb_lab related documents
    [pcb_lab.kicad_pcb, pcb_lab.kicad_sch]
2024-01-18 Modify pcb_lab related documents
    [pcb_lab.kicad_sch]
2024-01-19 Add the content about stepper motor diver breakout board
2024-02-07 update with battery estimate
    [Display_Power Model_Wanling.xlsx, Sensing_Power Model_Wanling.xlsx, pcb_lab.kicad_pcb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]
2024-02-07 upload newest pcb design
    [APA102 2020 LED.step, Adafruit DotStar 2020 8x8 Matrix .step, B02B-XASK-1-A.STEP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]
2024-02-08 update newest pcb design
    [APA102 2020 LED.step, Adafruit DotStar 2020 8x8 Matrix .step, B02B-XASK-1-A.STEP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]
2024-02-13 update 3D model
    [pcb_lab.kicad_pcb]
2024-02-13 update model
    [APA102 2020 LED.step, Adafruit DotStar 2020 8x8 Matrix .step, B02B-XASK-1-A.STEP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]
2024-02-21 updade 2nd device
    [APA102 2020 LED.step, Adafruit DotStar 2020 8x8 Matrix .step, B02B-XASK-1-A.STEP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]
